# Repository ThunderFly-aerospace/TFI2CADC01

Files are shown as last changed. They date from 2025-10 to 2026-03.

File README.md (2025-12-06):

# TFI2CADC01 — I²C 16‑bit ADC for UAVs

Compact 4‑channel analog‑to‑digital converter module for Pixhawk‑class autopilots and ThunderFly form‑factor carrier boards. Based on [TI ADS1115 (16‑bit Σ‑Δ ADC)](https://www.ti.com/lit/ds/symlink/ads1115.pdf?ts=1741234332539). Dual Pixhawk JST‑GH I²C ports support in‑line daisy‑chaining.

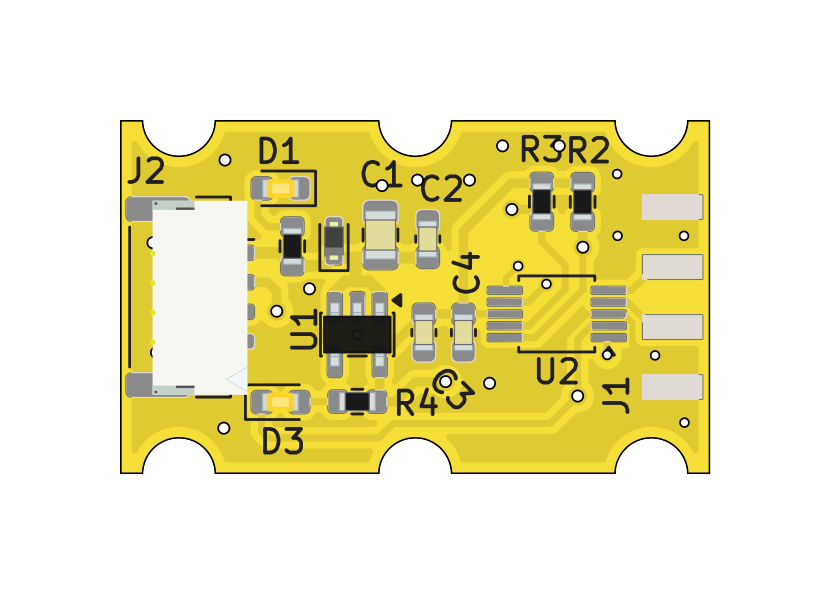
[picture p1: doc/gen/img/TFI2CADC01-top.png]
TFI2CADC01 top view

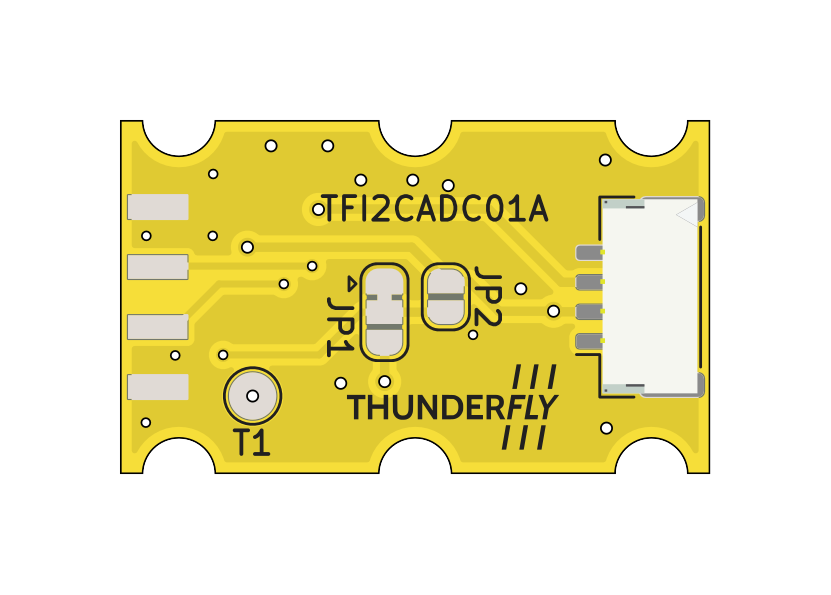
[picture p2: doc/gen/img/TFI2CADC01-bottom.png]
TFI2CADC01 bottom view


## Key features

* 4 × single‑ended inputs (AIN0…AIN3) up to VDD range (0–3.3 V)
* 16‑bit ADC (ADS1115IDGS) with programmable gain amplifier (PGA)
* I²C interface, 100/400 kHz compliant; on‑board 4.7 kΩ pull‑ups to 3.3 V
* ADDR solder-bridge for selectable I²C address (default 0x48)
* ALERT/RDY interrupt output (optional test‑point)
* Bus‑powered from +5 V; on‑board LDO to internal 3.3 V
* Input/rail protection and status LEDs (PWR, activity)
* Two JST‑GH 4‑pin I²C ports for Pixhawk; one 2×4 header for access to analog inputs and ground

## Electrical

* **Input supply (JST‑GH VBUS):** 5.4 V (Pixhawk I²C standard)
* **I²C levels:** 3.3 V (pull‑ups on board)
* **Analog input range:** 0…3.3 V (referenced to GND)
* **ESD / surge:** front‑end and bus clamped (5.6 V TVS on 5 V)

> ⚠️ Do **not** exceed 3.3 V on AINx relative to GND.

## Connectors & pinout

### JST‑GH I²C (J2, J3) — Pixhawk standard

```
Pin 1: VBUS +5V
Pin 2: SCL
Pin 3: SDA
Pin 4: GND
```

Both ports are wired in parallel for pass‑through/daisy‑chain.

### I²C addressing

Default assembly is 0x48.

| ADDR input  | 7‑bit I²C address |
| --- | --- |
| GND | 0x48 (default) |
| VDD (3.3 V) | 0x49 |
| SDA | 0x4A |
| SCL | 0x4B |

> The board provides pads/jumper position for changing the address. See silkscreen near ADDR.

## Jumpers / test points

* **T1 (ALERT/RDY):** routes the ALERT/RDY pin to a test pad for optional host interrupt. Leave open if unused.
* **JP2/JP2:** board address option tie (factory) to 3.3 V.

## LEDs

* **PWR (green):** 3.3 V power rail present.
* **ACT (orange):** activity/diagnostic (wired to logic as per schematic option).

## Typical wiring (Pixhawk)

1. Plug either JST‑GH port to a Pixhawk I2C port (5 V provided by autopilot).
2. Daisy‑chain additional I²C node from the second JST‑GH if needed.
3. Connect sensors to AIN0…AIN3 via J1, or wire your signals to the corresponding pads.
4. (Optional) Strap ADDR and solder for a non‑default address if multiple TFI2CADC01 are present on the same I2C bus.

## Software notes (ADS1115)

* **PX4 support:** PX4 Autopilot includes a native driver for ADS1115 (16‑bit, up to 860 SPS, 4‑channel delta‑sigma ADC with PGA, oscillator, internal VREF, comparator and I²C). See [PX4 driver](https://github.com/PX4/PX4-Autopilot/tree/main/src/drivers/adc/ads1115) and [TI ADS1115](https://www.ti.com/product/ADS1115).
* **Use cases:** Pixhawk‑compatible ADC module is suitable for prototyping/attaching analog‑output sensors (e.g., temperature, humidity, gas presence, etc.).
* **Configuration tips:** configure PGA for expected full‑scale to maximize resolution; for single‑ended reads use MUX AIN0/1/2/3 vs GND; to minimize I²C polling enable comparator in "traditional" mode and read **ALERT/RDY** (if T1 is wired).

### Example (Linux `i2c-tools`)

```bash
# Detect
sudo i2cdetect -y 1

# Read a register (conversion register 0x00)
sudo i2cget -y 1 0x48 0x00 w
```

## Mechanical & form factor

PCB follows the **ThunderFly form factor** for avionics modules (mounting & stacking compatible with TF carriers). Two JST‑GH side‑by‑side for easy in‑line installation inside UAV wiring harnesses.

## Revision history

  - TFI2CADC01A - Initial revision

## Availability and Customization

The TFI2CADC01 is available from ThunderFly s.r.o. For a commercial quotation, contact us at [sale@thunderfly.cz](mailto:sale@thunderfly.cz) or shop via our Lectronz or Tindie store.

We also offer application‑specific modifications on request. Typical options include alternative input scaling (dividers/shunts), connector or cable variations, pre‑strapped I²C addresses, and simple mounting adaptations. Basic changes are usually provided at no additional cost with an estimated lead time of approximately three weeks.

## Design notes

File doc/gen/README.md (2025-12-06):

# PCB

Board size: 25.0x15.0 mm (0.98x0.59 inches)

- This is the size of the rectangle that contains the board
- Thickness: 1.6 mm (63 mils)
- Material: FR4
- Finish: HAL lead-free
- Layers: 2
- Copper thickness: 35 µm

Solder mask: TOP / BOTTOM

- Color: Green

Silk screen: TOP / BOTTOM

- Color: White

Stackup:

| Name | Type | Color | Thickness [µm]| Material | Er | Loss tan |
|---|---|---|---|---|---|---|
| F.SilkS | Top Silk Screen | | | | | |
| F.Paste | Top Solder Paste | | | | | |
| F.Mask | Top Solder Mask | Green | 10 | | | |
| F.Cu | copper | | 35 | | | |
| dielectric 1 | core | | 1510 | FR4 | 4.5 | 0.020 |
| B.Cu | copper | | 35 | | | |
| B.Mask | Bottom Solder Mask | Green | 10 | | | |
| B.Paste | Bottom Solder Paste  | | | | | |
| B.SilkS | Bottom Silk Screen | | | | | |

# Important sizes

Clearance: 0.2 mm (8 mils)

Track width: 0.2 mm (8 mils)

- By design rules: 0.2 mm (8 mils)

Drill: 0.4 mm (16 mils)

- Vias: 0.4 mm (16 mils) [Design: 0.4 mm (16 mils)]
- Pads: N/A mm (N/A mils)
- The above values are real drill sizes, they add 0.1 mm (4 mils) to plated holes (PTH)

Via: 0.6/0.3 mm (24/12 mils)

- By design rules: 0.4/0.3 mm (16/12 mils)
- Micro via: yes [0.2/0.1 mm (8/4 mils)]
- Buried/blind via: yes
- Total: 27 (thru: 27 buried/blind: 0 micro: 0)

Outer Annular Ring: 0.1 mm (4 mils)

- By design rules: N/A mm (N/A mils)

Eurocircuits class: 6C
- Using min drill 0.35 mm for an OAR of 0.13 mm

# General stats

Components count: (SMD/THT)

- Top: 15/0 (SMD)
- Bottom: 1/0 (SMD)

Defined tracks:

- 0.2 mm (8 mils)
- 0.25 mm (10 mils)
- 0.3 mm (12 mils)
- 0.4 mm (16 mils)
- 0.5 mm (20 mils)
- 0.6 mm (24 mils)

Used tracks:

- 0.2 mm (8 mils) (3) defined: yes
- 0.25 mm (10 mils) (13) defined: yes
- 0.3 mm (12 mils) (41) defined: yes
- 0.4 mm (16 mils) (41) defined: yes
- 0.5 mm (20 mils) (22) defined: yes
- 0.5 mm (20 mils) (2) defined: no

Defined vias:

Used vias:

- 0.6/0.3 mm (24/12 mils) (Count: 9, Aspect: 2.7 A) defined: no
- 0.8/0.4 mm (31/16 mils) (Count: 18, Aspect: 2.0 A) defined: no

Holes (excluding vias):

Oval holes:

Drill tools (including vias and computing adjusts and rounding):

- 0.4 mm (16 mils) (9)
- 0.5 mm (20 mils) (18)

Solder paste stats:

Using a paste with 87.75 % alloy, that has an specific gravity for the alloy of 7.4 g/cm³
and 1.0 g/cm³ for the flux. This paste has an specific gravity of  4.15 g/cm³.

The stencil thickness is  0.12 mm.

| Side | Pads with paste | Area [mm²] | Paste [g] |
|---|---|---|---|
| Top | 43 | 34.80 | 0.17 |
| Bottom | 6 | 9.28 | 0.05 |
| Total  | 49 | 44.07 | 0.22 |

Note: this is just an approximation to the theoretical value. Margins of the solder mask and waste aren't computed.

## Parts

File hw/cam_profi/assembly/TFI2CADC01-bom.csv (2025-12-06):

Component | Description | Part | References | Value | Footprint | Quantity Per PCB | Datasheet | ust_id
1 | Unpolarized capacitor | C | C2C4 | 100nF | C_0603_1608Metric | 2 | ~ | 5c70984812875079b91f8bf2
2 | Unpolarized capacitor | C | C3 | 1uF | C_0603_1608Metric | 1 | ~ | 5c70984812875079b91f8bc2
3 | Unpolarized capacitor | C | C1 | 10uF | C_0805_2012Metric | 1 | ~ | 5c70984812875079b91f8bbd
4 | Light emitting diode | LED | D3 | ALERT | LED_0603_1608Metric | 1 | ~ | 60d581db1287500165f859a2
5 |  | D_ZENER | D2 | BZX585-B5V6.115 | D_SOD-523 | 1 |  | 60879d38128750769ee58e48
6 | Light emitting diode | LED | D1 | PWR | LED_0603_1608Metric | 1 | ~ | 60d582331287500165f859d0
7 | 2x04 2.54 mm pitch header | HEADER_2x04 | J1 | HEADER_2x04 | PinHeader_2x04_P2.54mm_Edge_Mount | 1
8 |  | SM04B-GHS-TB | J2J3 | SM04B-GHS-TB | JST_GH_SM04B-GHS-TB_1x04-1MP_P1.25mm_Horizontal | 2 |  | 5c86273d1287500b4e0280be
9 | Resistor | R | R1 | 180R | R_0603_1608Metric | 1 | ~ | 5c70984512875079b91f8957
10 | Resistor | R | R4 | 4k7 | R_0603_1608Metric | 1 | ~ | 5c70984512875079b91f8962
11 | Resistor | R | R2R3 | 10k | R_0603_1608Metric | 2 | ~ | 5c70984512875079b91f8962
12 | Ultra-Small, Low-Power, I2C-Compatible, 860-SPS, 16-Bit ADCs With Internal Reference, Oscillator, and Programmable Comparator, VSSOP-10 | ADS1115IDGS | U2 | ADS1115IDGS | VSSOP-10_3x3mm_P0.5mm | 1 | http://www.ti.com/lit/ds/symlink/ads1113.pdf | 6934a81dea235ce78ba25ac5
13 | 300mA Low-dropout Voltage Regulator, Vout 3.3V, Vin up to 5.5V, SOT-23 | MIC5504-3.3YM5 | U1 | MIC5504-3.3YM5 | SOT-23-5 | 1 | http://ww1.microchip.com/downloads/en/DeviceDoc/MIC550X.pdf | 5c7255e81287500b4e112ea2

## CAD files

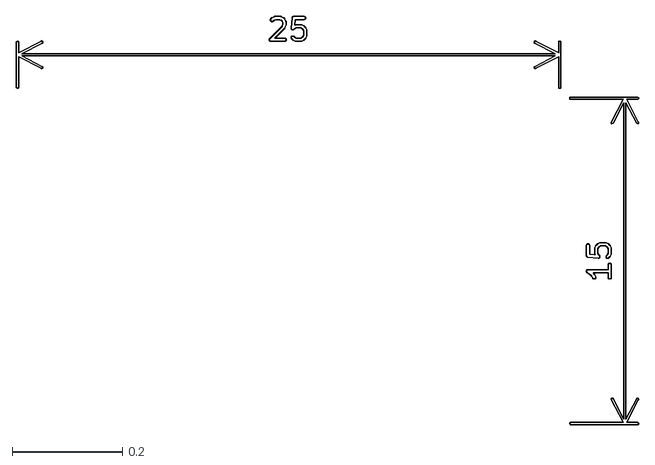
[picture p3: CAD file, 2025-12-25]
doc/gen/dxf/TFI2CADC01-User_Comments.dxf
1.13 x 0.741

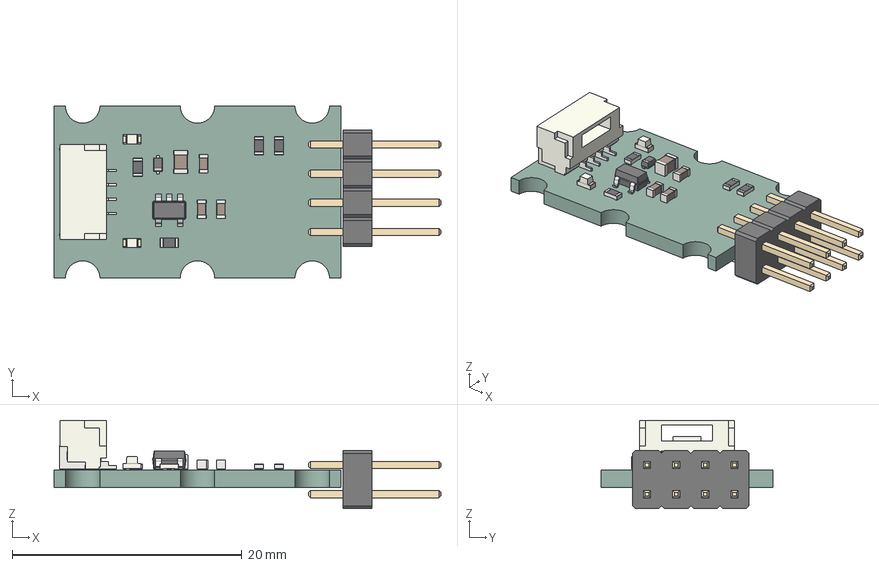
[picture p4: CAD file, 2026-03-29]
doc/gen/TFI2CADC01.step
33.7 x 15.0 x 7.70 mm
SOT-23-5
C_0603_1608Metric x 3
R_0603_1608Metric x 4
C_0805_2012Metric
D_SOD-523
LED_0603_1608Metric x 2
JST_GH_SM04B-GHS-TB_1x04-1MP_P1.25mm_Horizontal
PinHeader_2x04_P2.54mm_Vertical
kibot_foy_f035_PCB

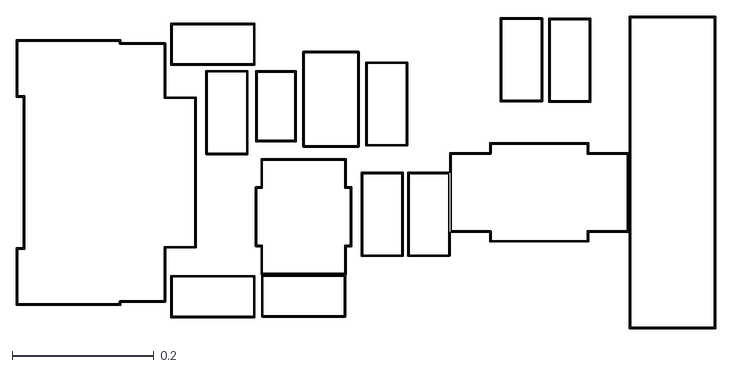
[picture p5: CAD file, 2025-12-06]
doc/gen/dxf/TFI2CADC01-F_Courtyard.dxf
0.987 x 0.441

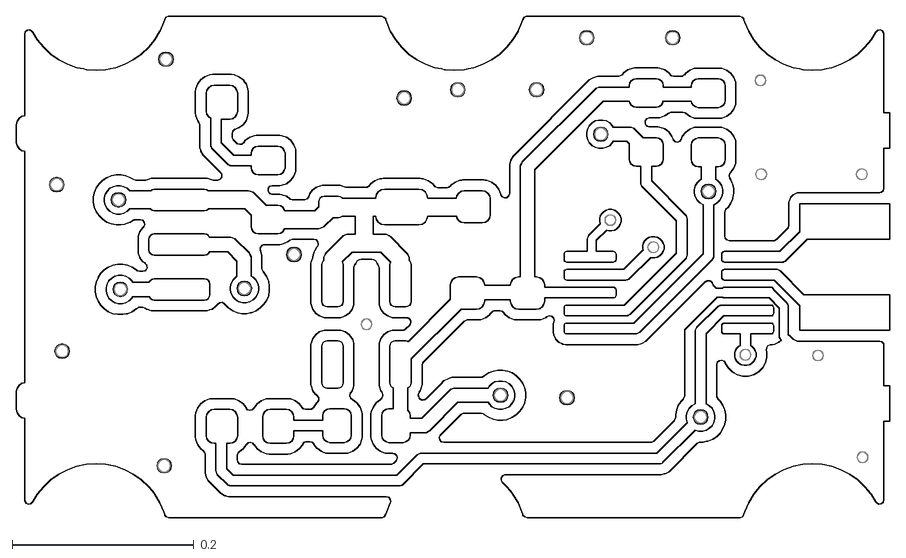
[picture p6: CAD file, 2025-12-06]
doc/gen/dxf/TFI2CADC01-F_Cu.dxf
0.96 x 0.551

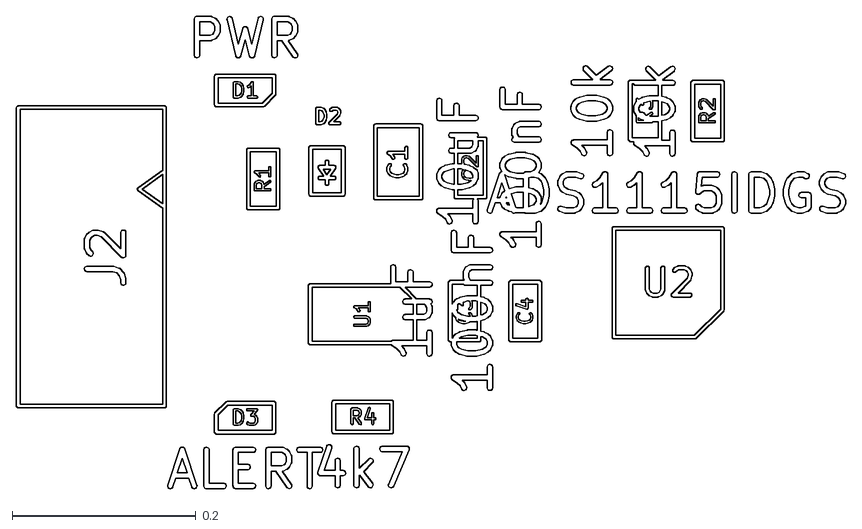
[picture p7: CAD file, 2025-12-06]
doc/gen/dxf/TFI2CADC01-F_Fab.dxf
0.903 x 0.514

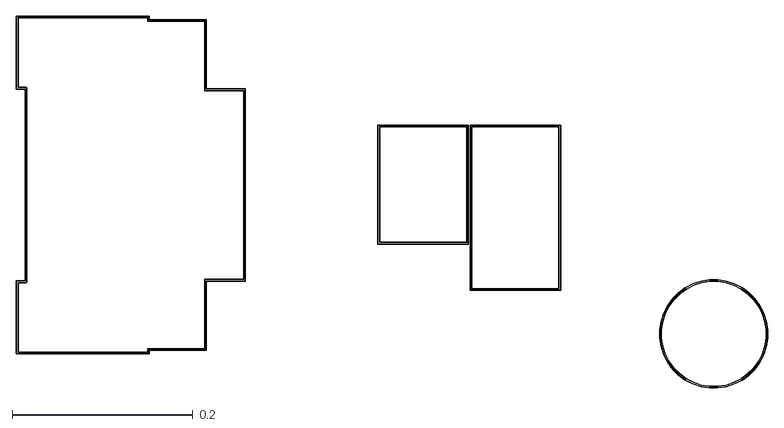
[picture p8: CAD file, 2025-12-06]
doc/gen/dxf/TFI2CADC01-B_Courtyard.dxf
0.833 x 0.412

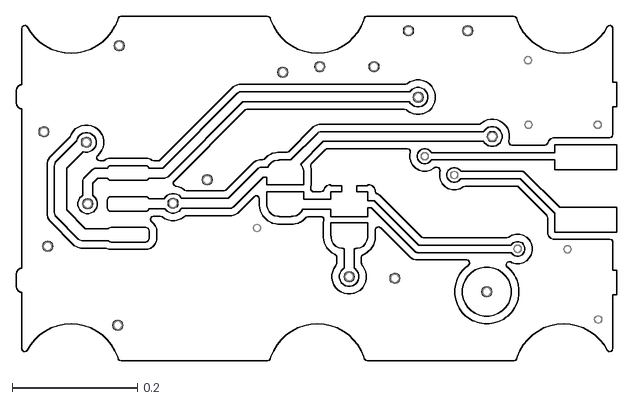
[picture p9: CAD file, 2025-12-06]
doc/gen/dxf/TFI2CADC01-B_Cu.dxf
0.96 x 0.551

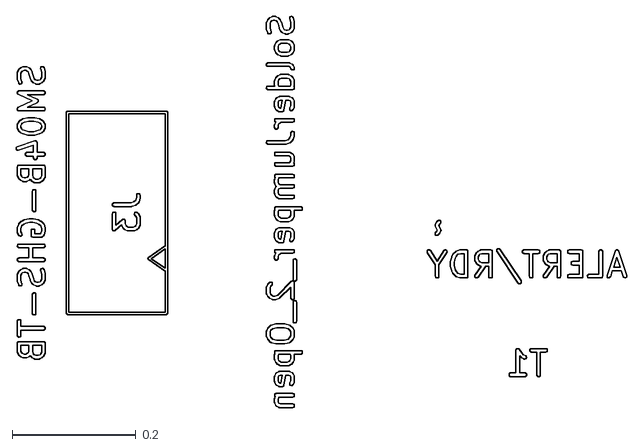
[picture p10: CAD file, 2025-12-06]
doc/gen/dxf/TFI2CADC01-B_Fab.dxf
0.987 x 0.632

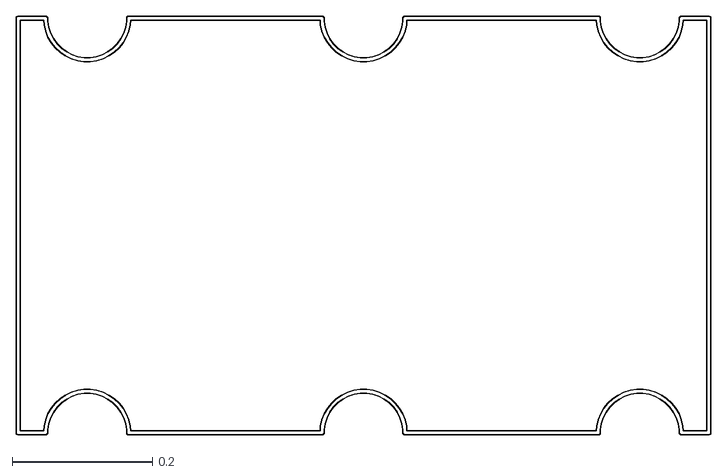
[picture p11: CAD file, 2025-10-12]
doc/gen/dxf/TFI2CADC01-Edge_Cuts.dxf
0.99 x 0.596

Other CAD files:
doc/gen/dxf/TFI2CADC01-Margin.dxf
doc/gen/dxf/TFI2CADC01-User_Drawings.dxf
doc/gen/dxf/TFI2CADC01-B_Mask.dxf
doc/gen/dxf/TFI2CADC01-B_Paste.dxf
doc/gen/dxf/TFI2CADC01-B_Silkscreen.dxf
doc/gen/dxf/TFI2CADC01-F_Mask.dxf
doc/gen/dxf/TFI2CADC01-F_Paste.dxf
doc/gen/dxf/TFI2CADC01-F_Silkscreen.dxf

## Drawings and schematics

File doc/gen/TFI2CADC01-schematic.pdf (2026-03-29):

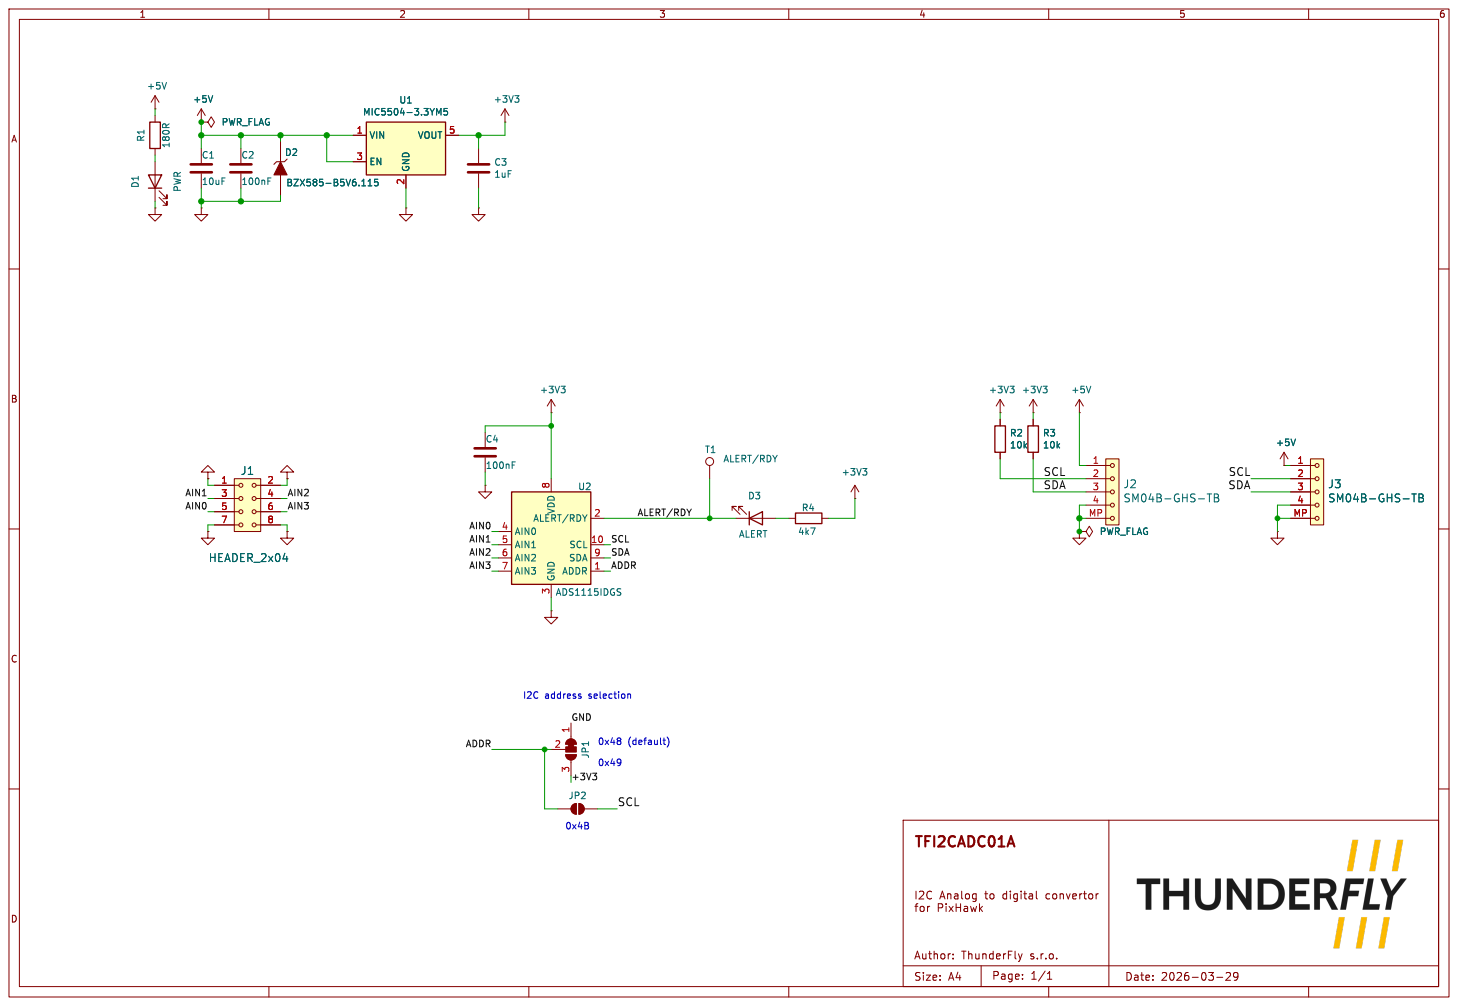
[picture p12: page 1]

3 ALERT/RDY 2 SCL 10 SDA 9 ADDR 1 U2 ADS1115IDGS
SCLSCL

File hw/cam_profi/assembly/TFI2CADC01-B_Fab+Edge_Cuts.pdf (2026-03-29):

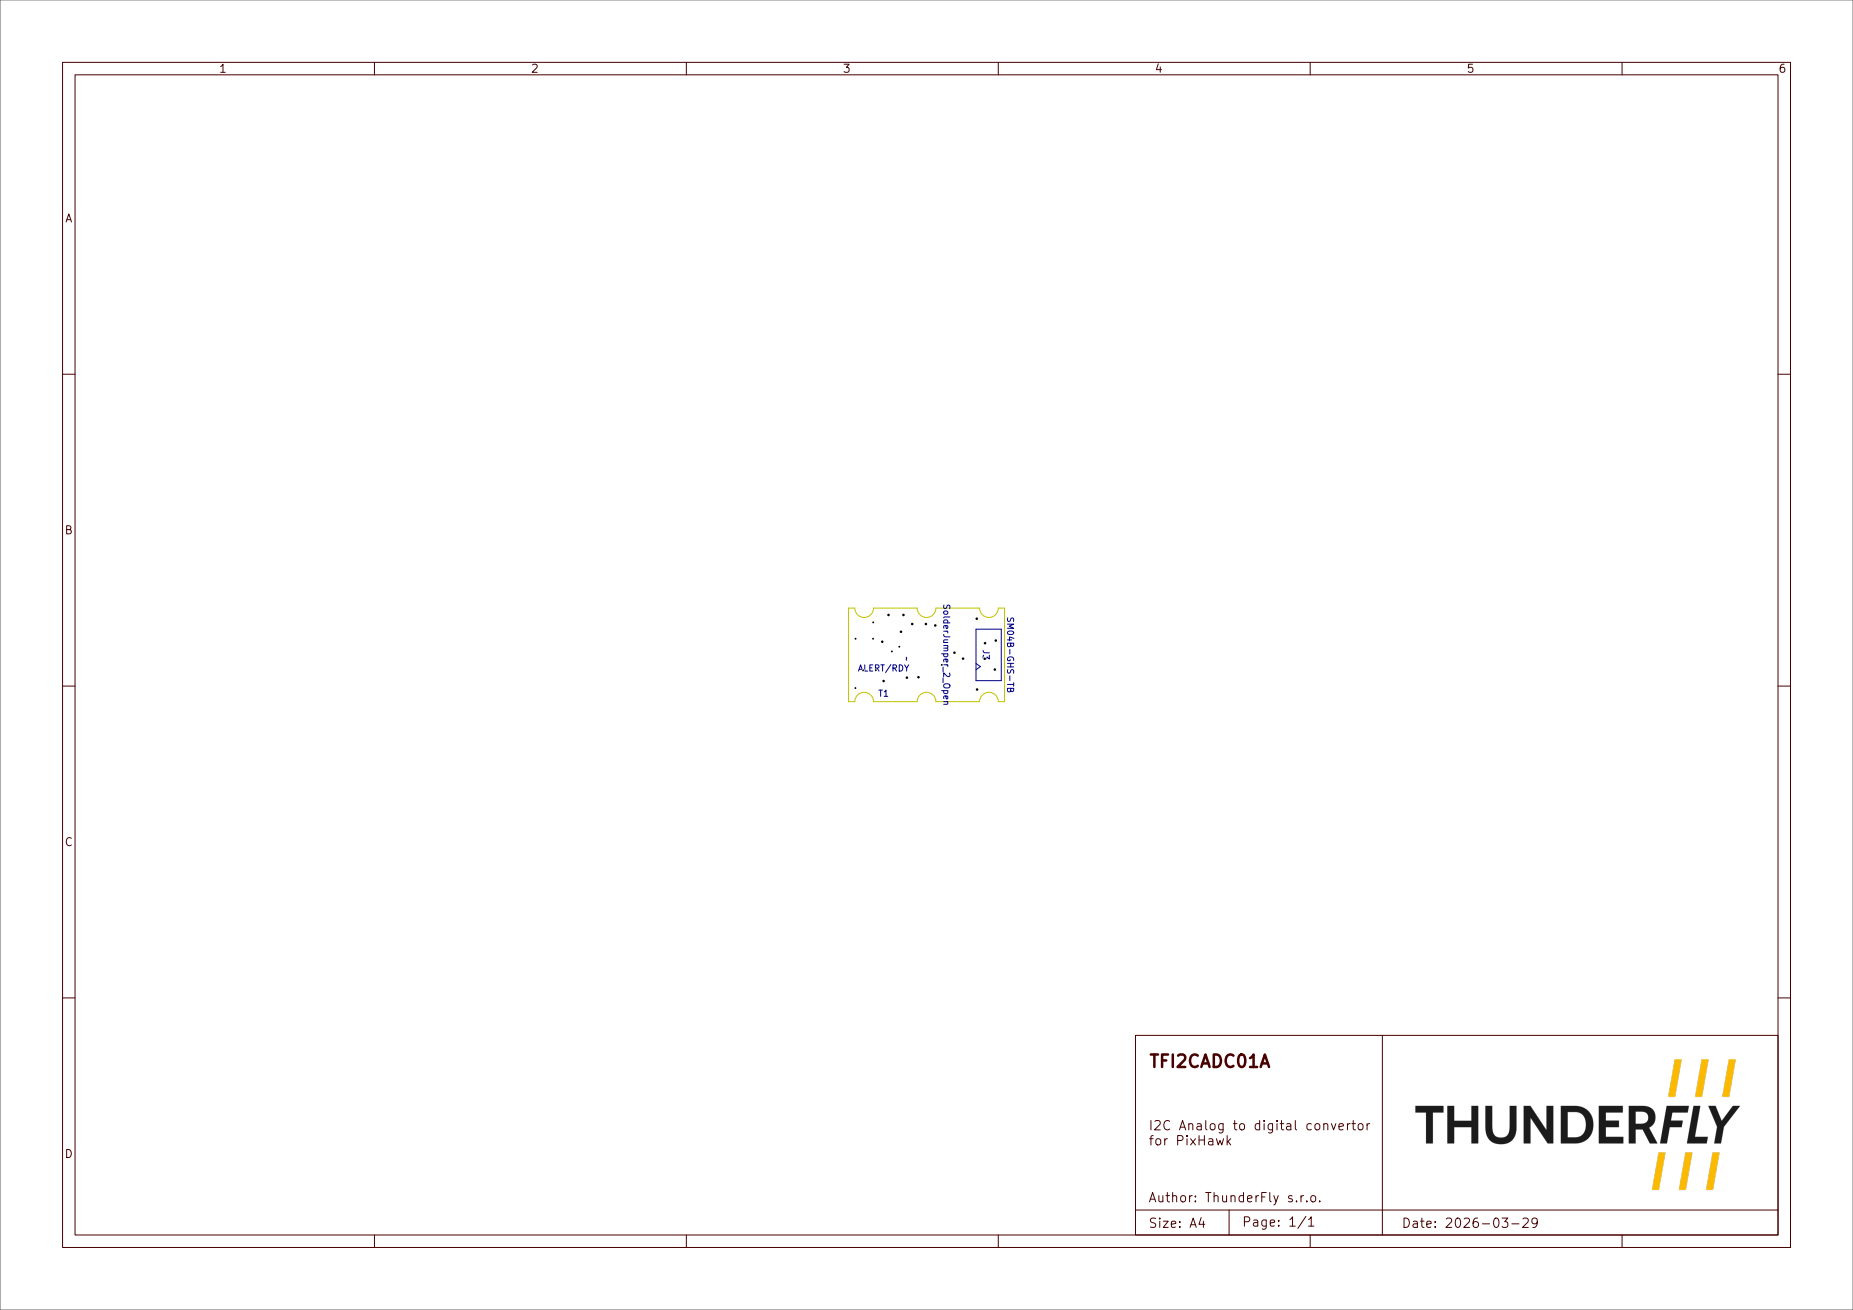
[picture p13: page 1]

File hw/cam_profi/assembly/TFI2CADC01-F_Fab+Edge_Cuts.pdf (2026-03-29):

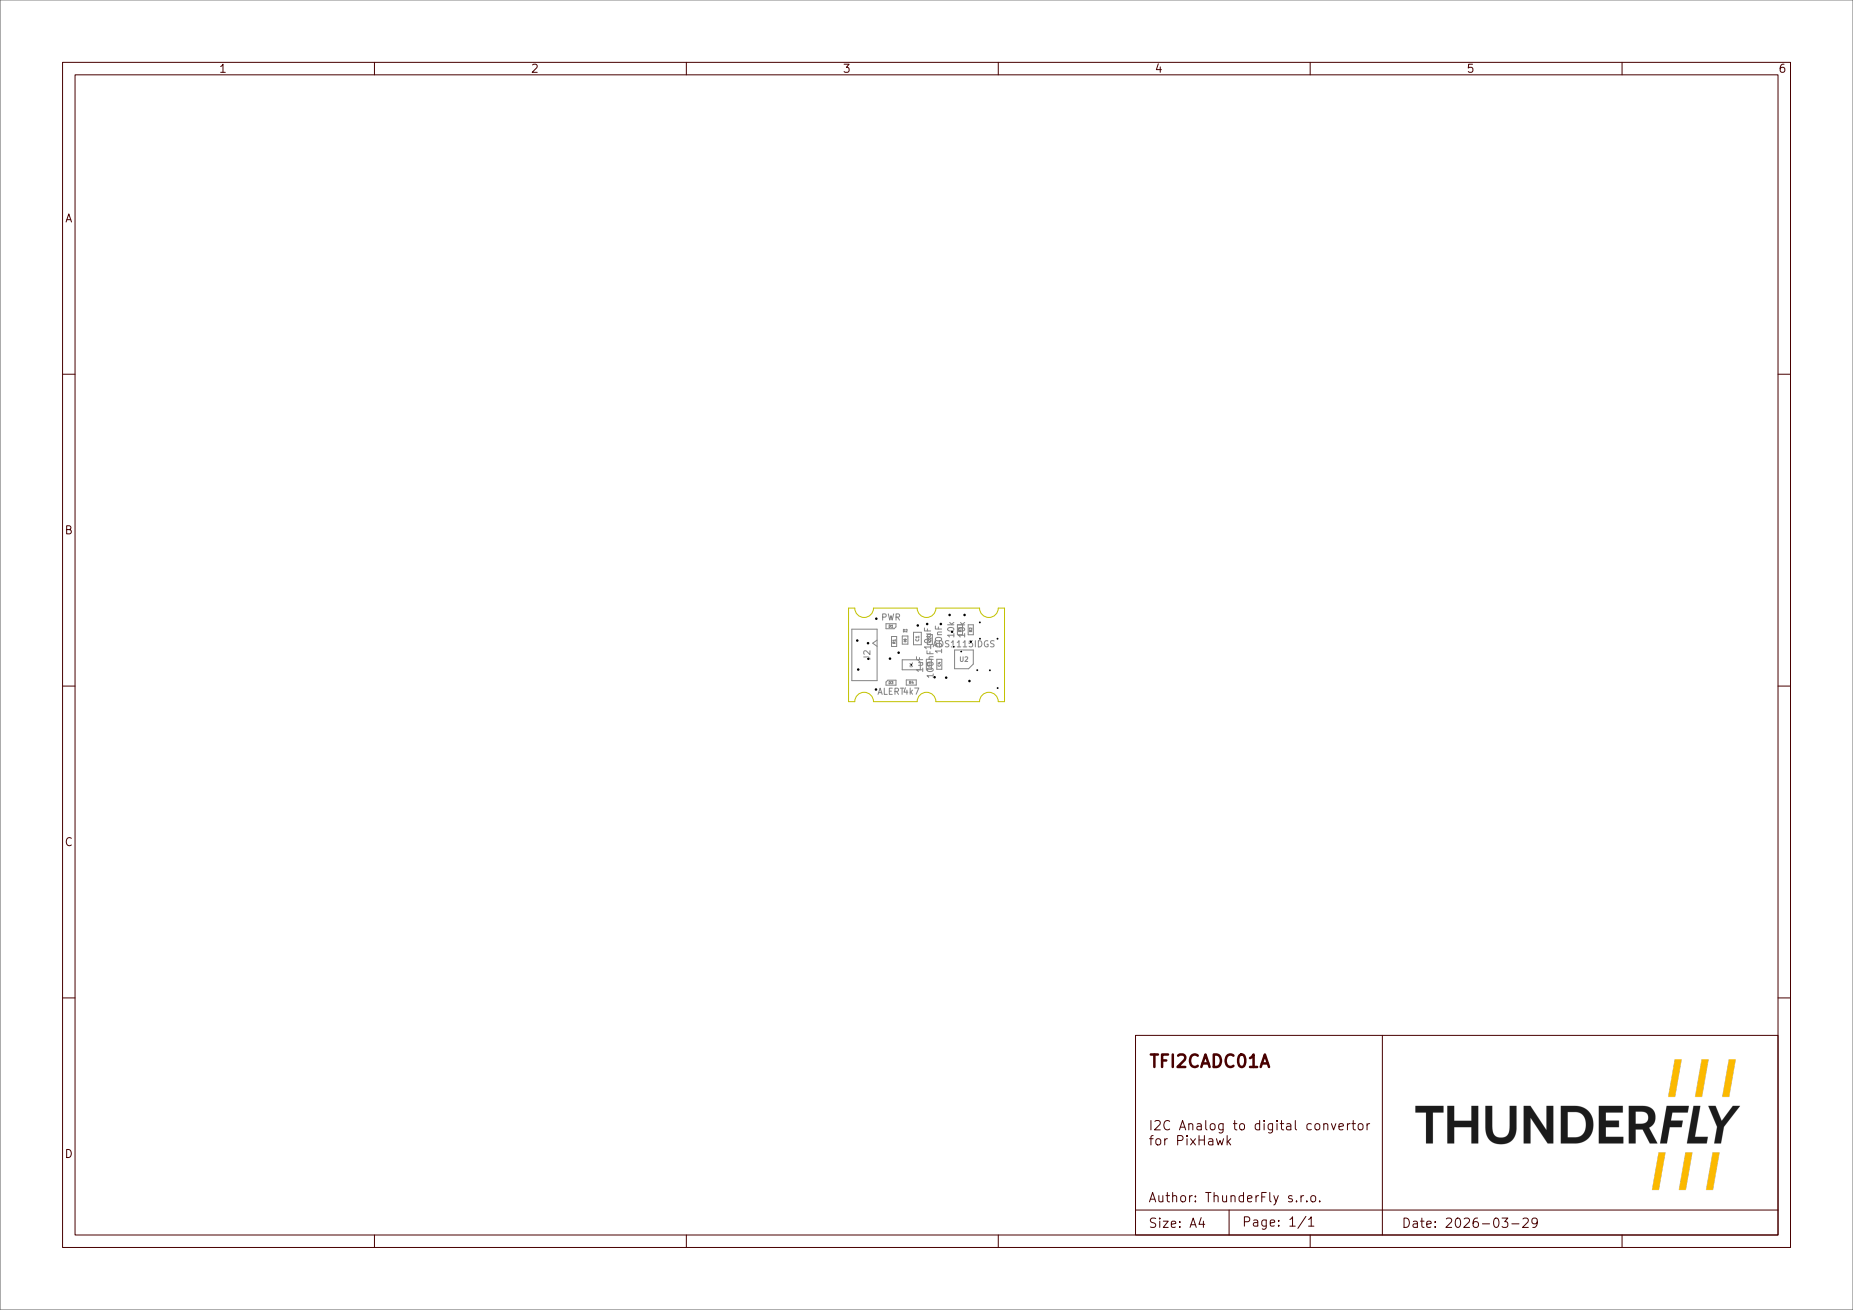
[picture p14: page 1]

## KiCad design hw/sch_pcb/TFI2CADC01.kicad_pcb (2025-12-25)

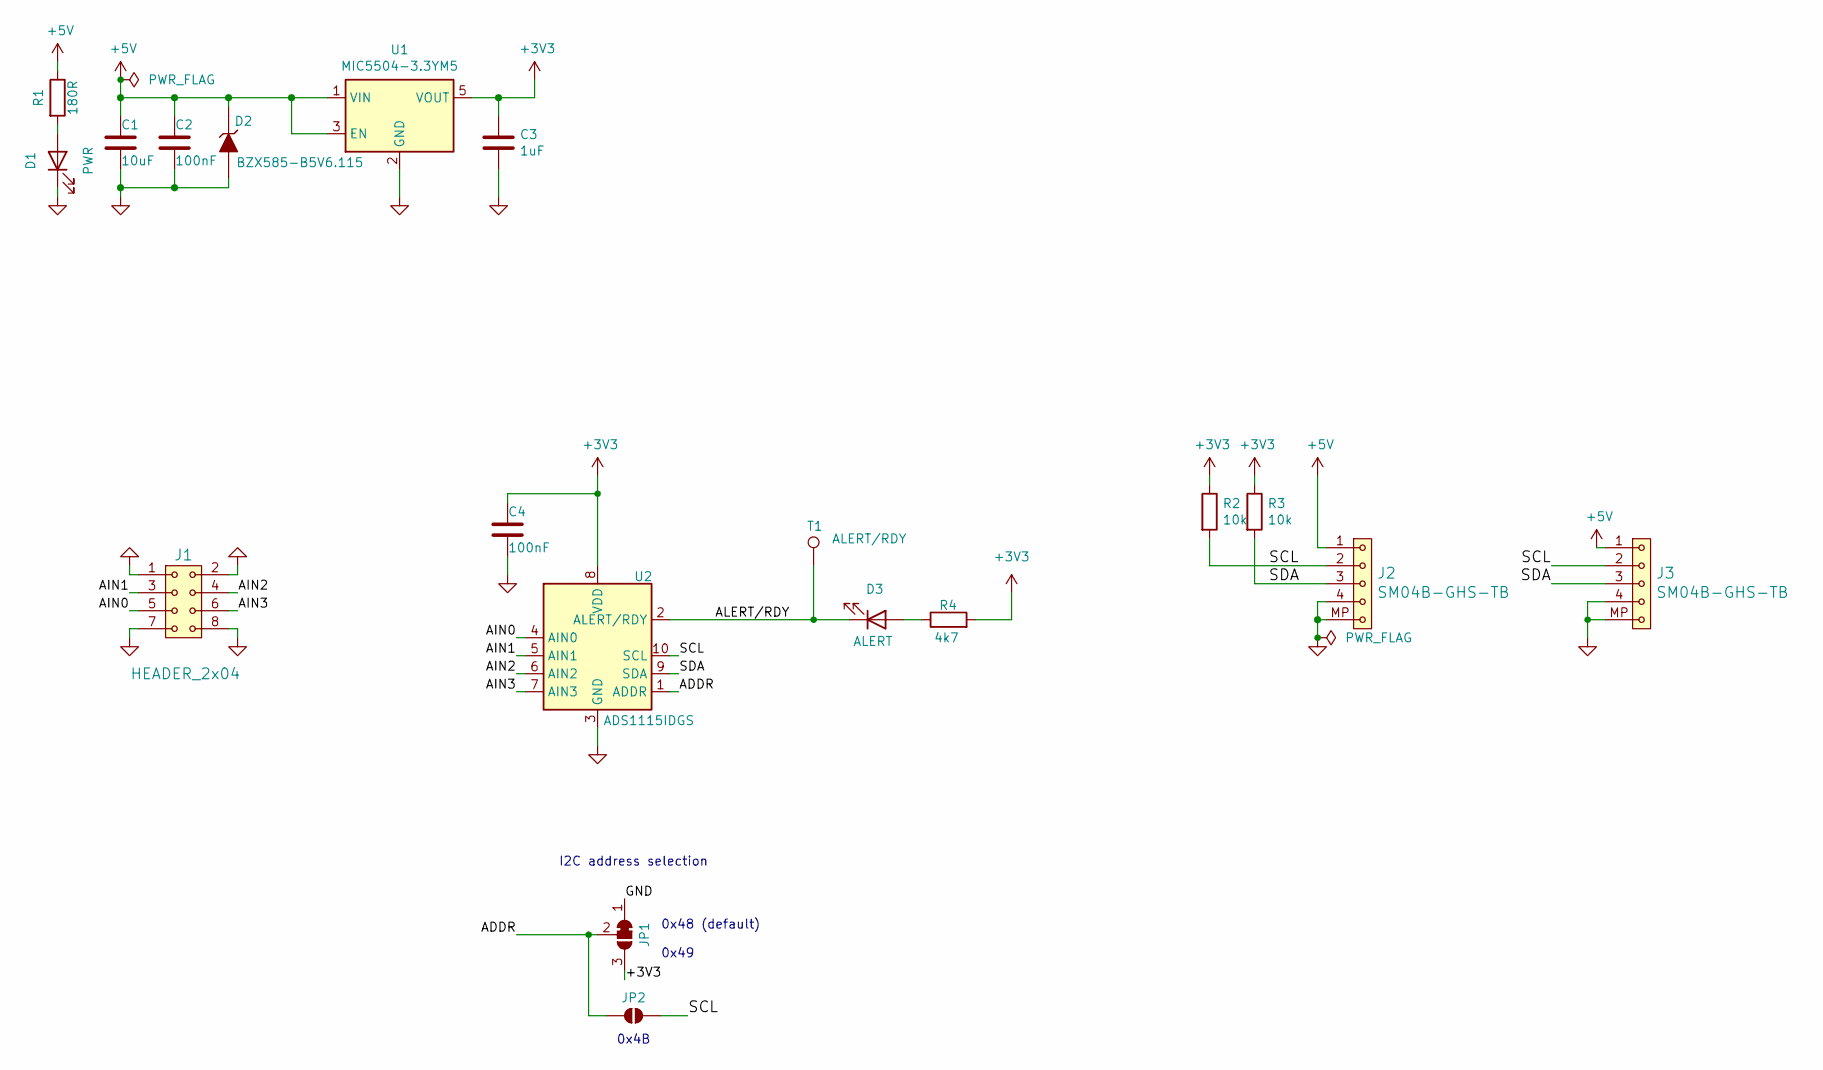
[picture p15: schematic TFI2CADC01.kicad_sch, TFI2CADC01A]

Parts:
C1: 10uF; C_0805_2012Metric
C2, C4: 100nF; C_0603_1608Metric
C3: 1uF; C_0603_1608Metric
D1: PWR; LED_0603_1608Metric
D2: BZX585-B5V6.115; D_SOD-523
D3: ALERT; LED_0603_1608Metric
J1: HEADER_2x04; PinHeader_2x04_P2.54mm_Edge_Mount
J2, J3: SM04B-GHS-TB; JST_GH_SM04B-GHS-TB_1x04-1MP_P1.25mm_Horizontal
JP1: SolderJumper-3_P1.3mm_Bridged12_RoundedPad1.0x1.5mm
JP2: SolderJumper_2_Open; SolderJumper-2_P1.3mm_Open_RoundedPad1.0x1.5mm
R1: 180R; R_0603_1608Metric
R2, R3: 10k; R_0603_1608Metric
R4: 4k7; R_0603_1608Metric
T1: ALERT/RDY; TestPoint_Pad_D2.0mm
U1: MIC5504-3.3YM5; SOT-23-5
U2: ADS1115IDGS; VSSOP-10_3x3mm_P0.5mm

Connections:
+3V3: C3.1, C4.1, JP1.3 (B), R2.1, R3.1, R4.2, U1.5 (VOUT), U2.8 (VDD)
+5V: C1.1, C2.1, D2.1 (K), J2.1, J3.1, R1.1, U1.1 (VIN), U1.3 (EN)
/ADDR: JP1.2 (C), JP2.1 (A), U2.1 (ADDR)
/AIN0: J1.5, U2.4 (AIN0)
/AIN1: J1.3, U2.5 (AIN1)
/AIN2: J1.4, U2.6 (AIN2)
/AIN3: J1.6, U2.7 (AIN3)
/ALERT/RDY: D3.1 (K), T1.1, U2.2 (ALERT/RDY)
/SCL: J2.2, J3.2, JP2.2 (B), R2.2, U2.10 (SCL)
/SDA: J2.3, J3.3, R3.2, U2.9 (SDA)
GND: C1.2, C2.2, C3.2, C4.2, D1.1 (K), D2.2 (A), J1.1, J1.2, J1.7, J1.8, J2.4, J2.MP, J3.4, J3.MP, JP1.1 (A), U1.2 (GND), U2.3 (GND)
unnamed: D1.2 (A), R1.2
unnamed: D3.2 (A), R4.1

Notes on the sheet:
0x48 (default)
I2C address selection
0x4B
0x49

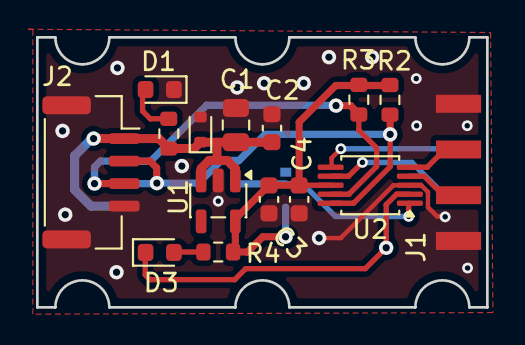
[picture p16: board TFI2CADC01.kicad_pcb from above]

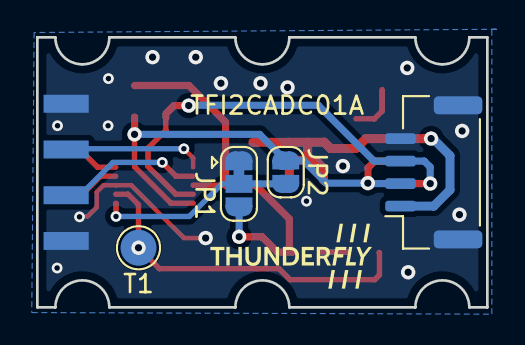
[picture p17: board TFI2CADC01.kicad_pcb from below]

Board: 2 copper layers, 25.0 x 15.0 mm, 19 parts (4 on the bottom side), 13 nets.

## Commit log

2025-09-26 Initial design for modification.
    [TFI2CADC01.kicad_pcb, TFI2CADC01.kicad_sch]
2025-09-26 Update actions products
    [TFI2CADC01-B_Courtyard.dxf, TFI2CADC01-B_Cu.dxf, TFI2CADC01-B_Fab.dxf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]
2025-10-01 Hotové schéma - otázka jumpery a konektory na vstupu
    [TFI2CADC01.kicad_pcb, TFI2CADC01.kicad_sch]
2025-10-02 ADS1115 obvod s headry
    [TFI2CADC01.kicad_pcb, TFI2CADC01.kicad_sch]
2025-10-02 Adding address selection
    [TFI2CADC01.kicad_sch]
2025-10-02 Updating footprints
    [TFI2CADC01.kicad_pcb, TFI2CADC01.kicad_sch]
2025-10-02 Updating schematics
    [TFI2CADC01.kicad_pcb, TFI2CADC01.kicad_sch]
2025-10-02 Add testpoint to Alert pin.
    [TFI2CADC01.kicad_sch]
2025-10-11 Adding pcb
    [TFI2CADC01.kicad_pcb, TFI2CADC01.kicad_sch]
2025-10-11 Improve layout.
    [TFI2CADC01.kicad_pcb]
2025-10-13 Updating pcb
    [TFI2CADC01.kicad_pcb]
2025-10-15 Improve silkscreen.
    [TFI2CADC01.kicad_pcb]
2025-12-06 Improve layout. Fix DRC and ERC errors. Improve PinHeader edge-mount footprint. Update footprints.
    [TFI2CADC01.kicad_pcb, TFI2CADC01.kicad_sch]
2025-12-06 Improve footprint selection. Fix layout Documentation update.
    [TFI2CADC01.kicad_pcb, TFI2CADC01.kicad_sch]
2025-12-25 Add PCB dimensions.
    [TFI2CADC01.kicad_pcb]
2026-02-15 Automatic update of KiCAD outputs
    [TFI2CADC01.step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]
